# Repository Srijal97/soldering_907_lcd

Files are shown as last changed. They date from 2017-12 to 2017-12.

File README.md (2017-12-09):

# Soldering Iron Controller for Hakko 907
This is a project based on 'Soldering Iron Controller for Hakko 907 v.2', by Alexander (sfrwmaker).
- [Hackster](https://www.hackster.io/sfrwmaker/soldering-iron-controller-for-hakko-907-v-2-fc75d7)
- [Instructables](http://www.instructables.com/id/Soldering-Iron-Controller-for-Hakko-907/)
- [GitHub](https://github.com/sfrwmaker/soldering_907_lcd)

A PCB with support for OLED display instead of 8x2 alphanumeric LCD has been made on eagle. The iron works great and heats to:
- 200C in 20secs
- 250C in 51secs
- 300C in 1min, 14secs
- 350C in 1min, 34secs

on a 19V DC Power Supply. It would be much faster on a 24V supply.





I have 5 extra PCBs left, which I won't be using. So, if anybody wants one, I'll send it to you for just the shipping cost from Mumbai, India to your place. 



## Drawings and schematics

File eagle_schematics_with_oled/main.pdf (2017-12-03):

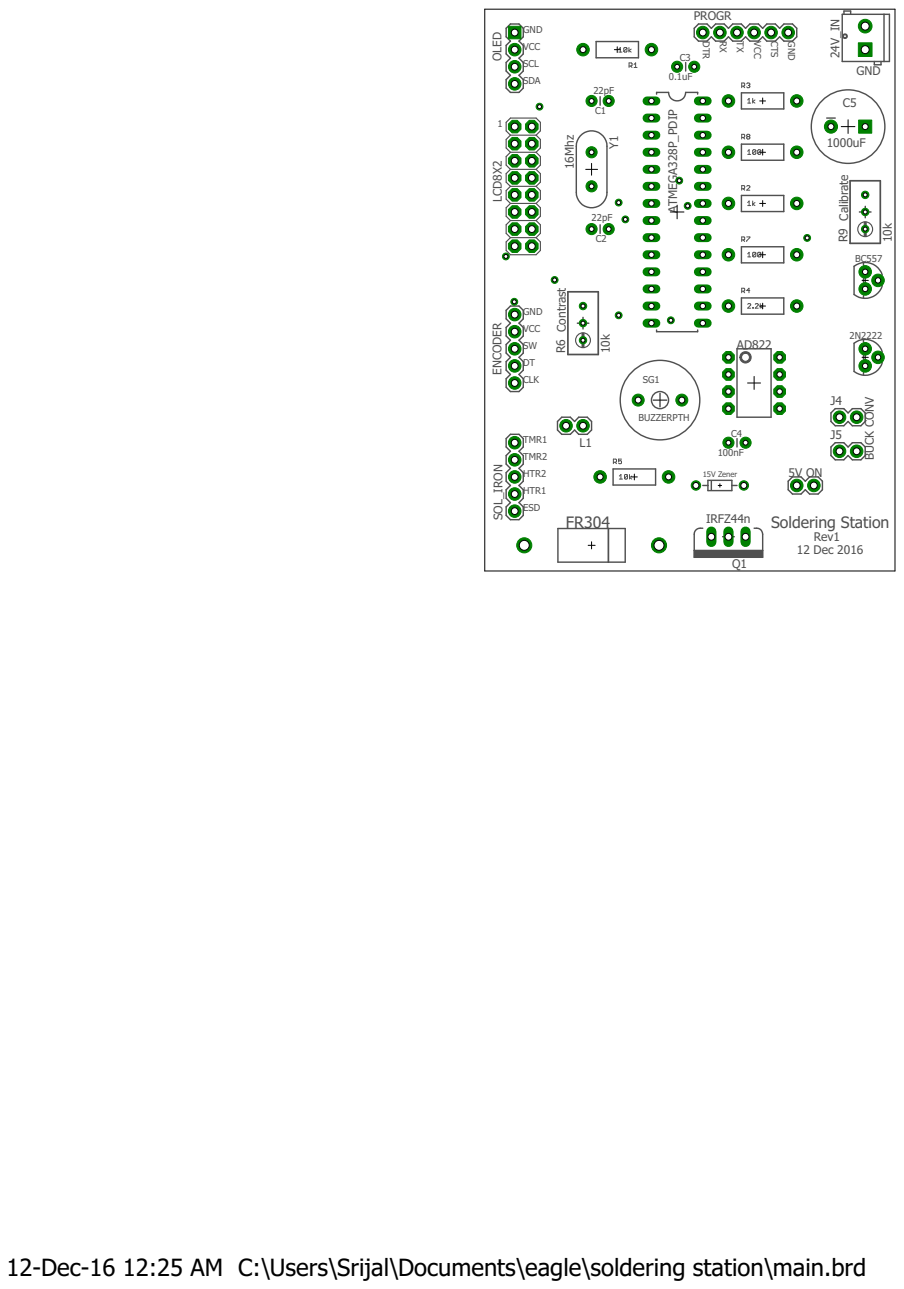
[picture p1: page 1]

12-Dec-16 12:25 AM C:\Users\Srijal\Documents\eagle\soldering station\main.brd

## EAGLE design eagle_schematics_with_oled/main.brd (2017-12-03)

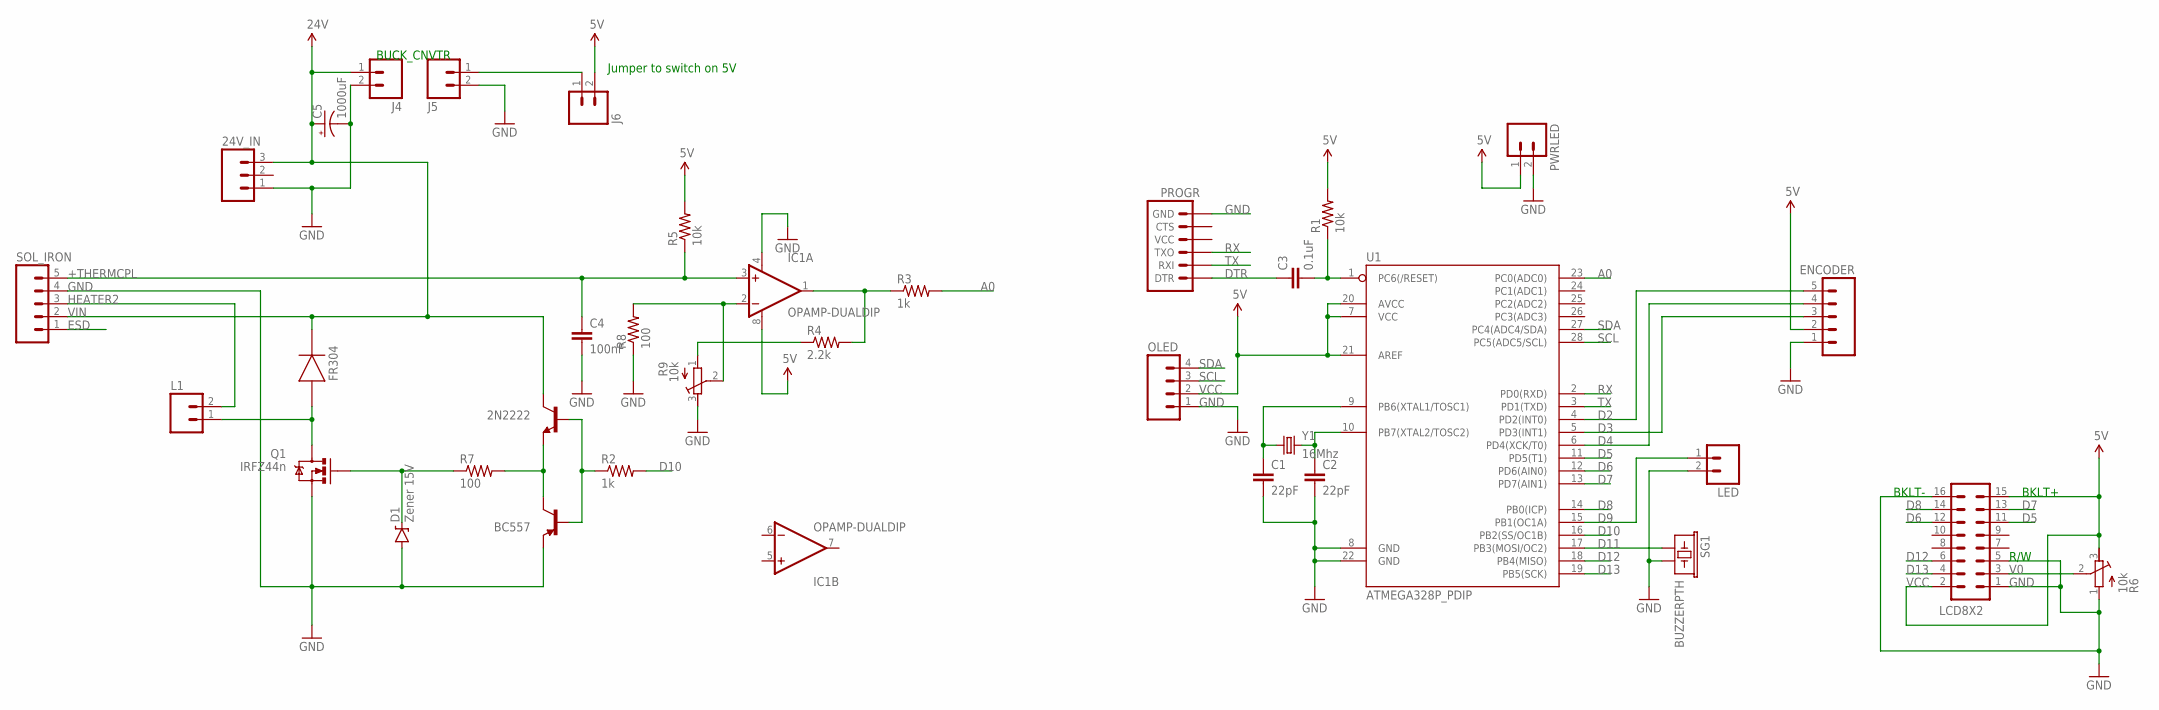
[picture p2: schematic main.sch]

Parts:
2N2222: TRANSISTOR_NPNP2N2222A; TO-92
24V_IN: M03PTH; 1X03
BC557: TRANSISTOR_PNPTO92; TO-92
C1, C2: 22pF; CAP-PTH-SMALL
C3: 0.1uF; CAP-PTH-SMALL
C4: 100nF; CAP-PTH-SMALL
C5: 1000uF; CPOL-RADIAL-1000UF-25V
D1: Zener 15V; DIODE-ZENER
ENCODER: M05PTH; 1X05
IC1: OPAMP-DUALDIP; DIP08
J4, J5, J6: M02PTH; 1X02
L1: M02PTH; 1X02
LCD8X2: M08X2; 2X8
LED: M02PTH; 1X02
OLED: M04PTH; 1X04
PROGR: ARDUINO_SERIAL_PROGRAMPTH; 1X06
PWRLED: M02PTH; 1X02
Q1: IRFZ44n; TO220V
R1, R5: 10k; AXIAL-0.4
R2, R3: 1k; AXIAL-0.4
R4: 2.2k; AXIAL-0.4
R6, R9: 10k; RTRIM3296W
R7, R8: 100; AXIAL-0.4
SG1: BUZZERPTH; BUZZER-12MM
SOL_IRON: M05PTH; 1X05
U1: ATMEGA328P_PDIP; DIL28-3
U$1: FR304
Y1: 16Mhz; HC49US

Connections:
+THERMCPL: C4.1, IC1.3 (+IN), R5.P$1 (1), SOL_IRON.5
A0: R3.P$2 (2), U1.23 (PC0(ADC0))
D2: ENCODER.5, U1.4 (PD2(INT0))
D3: ENCODER.3, U1.5 (PD3(INT1))
D4: ENCODER.4, U1.6 (PD4(XCK/T0))
D5: LCD8X2.11, U1.11 (PD5(T1))
D6: LCD8X2.12, U1.12 (PD6(AIN0))
D7: LCD8X2.13, U1.13 (PD7(AIN1))
D8: LCD8X2.14, U1.14 (PB0(ICP))
D9: LED.1, U1.15 (PB1(OC1A))
D10: R2.P$2 (2), U1.16 (PB2(SS/OC1B))
D11: SG1.+ (1), U1.17 (PB3(MOSI/OC2))
D12: LCD8X2.6, U1.18 (PB4(MISO))
D13: LCD8X2.4, U1.19 (PB5(SCK))
DTR: C3.1, PROGR.1 (DTR)
ESD: SOL_IRON.1
GND: 24V_IN.1, BC557.1 (E), C1.2, C2.2, C4.2, C5.-, D1.P$2 (A), ENCODER.1, IC1.4 (V-), J4.2, J5.2, LCD8X2.1, LCD8X2.5, LCD8X2.16, LED.2, OLED.1, PROGR.6 (GND), PWRLED.2, Q1.3 (S), R6.1 (A), R8.P$1 (1), R9.3 (E), SG1.- (2), SOL_IRON.4, U1.8 (GND), U1.22 (GND)
HEATER2: L1.2, SOL_IRON.3
unnamed: C1.1, U1.9 (PB6(XTAL1/TOSC1)), Y1.1
unnamed: C2.1, U1.10 (PB7(XTAL2/TOSC2)), Y1.2
unnamed: C3.2, R1.P$1 (1), U1.1 (PC6(/RESET))
unnamed: 2N2222.3 (E), BC557.3 (C), R7.P$2 (2)
unnamed: D1.P$1 (C), Q1.1 (G), R7.P$1 (1)
unnamed: L1.1, Q1.2 (D), U$1.A (ANODE)
unnamed: IC1.2 (-IN), R8.P$2 (2), R9.2 (S)
unnamed: 2N2222.2 (B), BC557.2 (B), R2.P$1 (1)
unnamed: IC1.1 (OUT), R3.P$1 (1), R4.P$2 (2)
unnamed: R4.P$1 (1), R9.1 (A)
unnamed: J5.1, J6.1
RX: PROGR.3 (TXO), U1.2 (PD0(RXD))
SCL: OLED.3, U1.28 (PC5(ADC5/SCL))
SDA: OLED.4, U1.27 (PC4(ADC4/SDA))
TX: PROGR.2 (RXI), U1.3 (PD1(TXD))
V0: LCD8X2.3, R6.2 (S)
VCC: ENCODER.2, IC1.8 (V+), J6.2, LCD8X2.2, LCD8X2.15, OLED.2, PWRLED.1, R1.P$2 (2), R5.P$2 (2), R6.3 (E), U1.7 (VCC), U1.20 (AVCC), U1.21 (AREF)
VIN: 2N2222.1 (C), 24V_IN.3, C5.+, J4.1, SOL_IRON.2, U$1.K (CATHODE)

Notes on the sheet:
BKLT+
BKLT-
R/W
BUCK_CNVTR
Jumper to switch on 5V

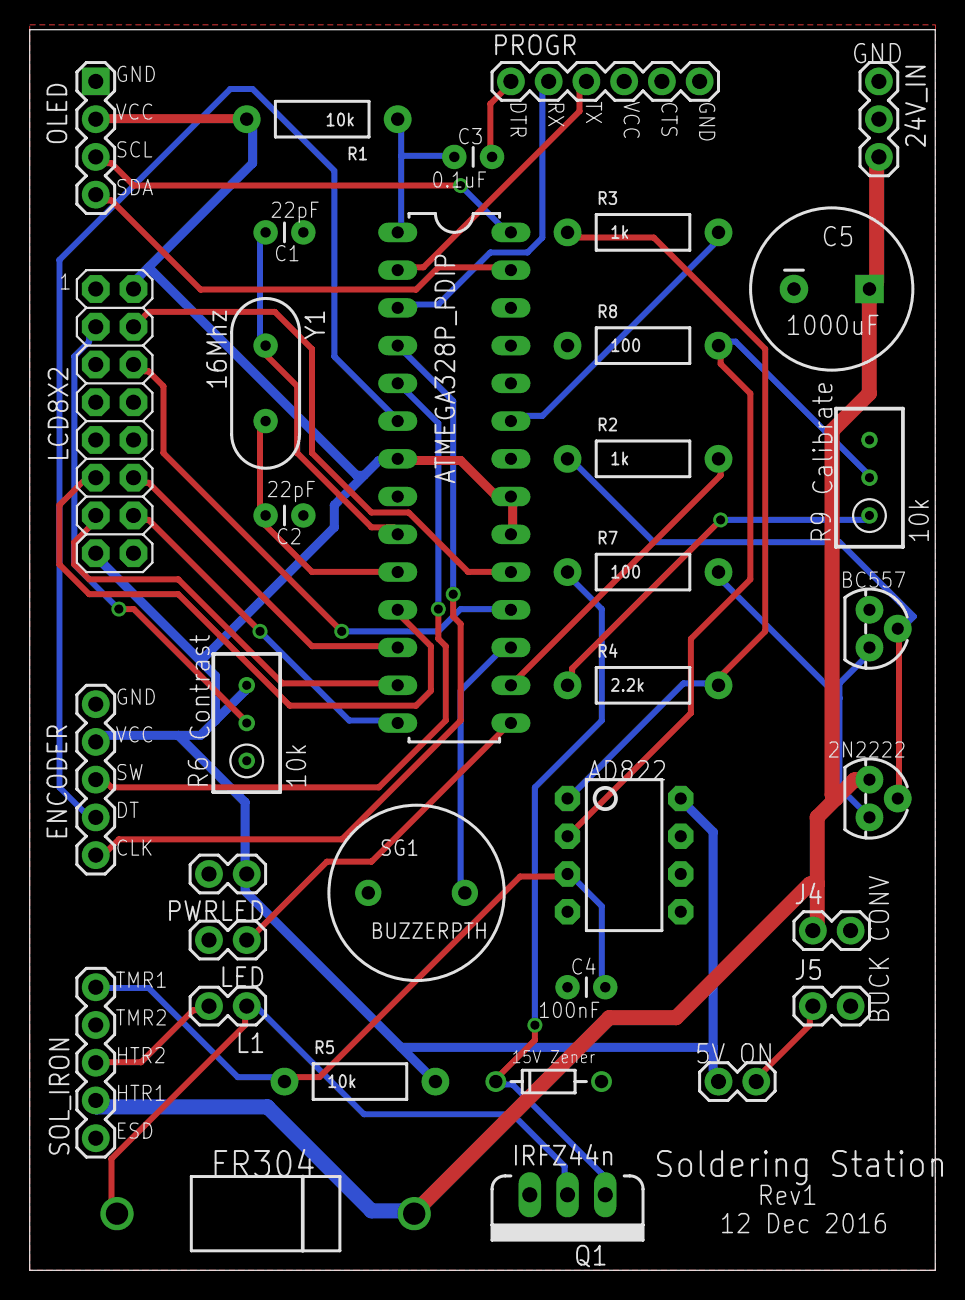
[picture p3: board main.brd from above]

Board: 2 copper layers, 60.9 x 83.5 mm, 35 parts (0 on the bottom side), 35 nets.

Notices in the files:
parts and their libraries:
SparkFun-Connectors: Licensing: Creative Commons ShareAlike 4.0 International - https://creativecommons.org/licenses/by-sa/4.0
